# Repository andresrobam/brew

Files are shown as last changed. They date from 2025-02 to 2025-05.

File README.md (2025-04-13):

# brew

Raspberry Pi based brewing controller.\
Written for and tested on a Raspberry Pi 4B running DietPi 9.9, but might work on other combinations.\
Requires docker and docker compose to be installed.
Runs on http://localhost:80. Port can be changed in the `docker-compose` file.

PID logic copied from [hirschmann/pid-autotune](https://github.com/hirschmann/pid-autotune).

## Issues

Fan tachometer signal reading does not work as intended and is hidden in the UI. Will be fixed in a future revision. \
Transistor footprints on the PCB have their pads very close together which makes soldering difficult. Will be changed for wider footprint in a future revision.

## GPIO pins

- GPIO04 (board 7) - Data channel of a DS18B20 temperature sensor (input)
- GPIO12 (board 32) - Fan PWM (output)
- GPIO13 (board 33) - PWM signal to drive the heater through a solid state relay (output)
- GPIO24 (board 18) - Buzzer (output)
- GPIO26 (board 37) - Fan tachometer signal (input)
- GPIO27 (board 13) - Pump relay control (output)

More details about the connections (necessary components and wiring) can be found in the `electronics` sub-directory (open with KiCad).

## Configuring temperature sensor and PWM modules

Add hardware PWM to boot configuration:

```
sudo echo -e "\ndtoverlay=pwm-2chan,pin=12,func=4,pin2=13,func2=4\n" >> /boot/config.txt
```

Add 1-Wire to boot configuration:

```
sudo echo -e "\ndtoverlay=w1-gpio\n" >> /boot/config.txt
```

Reboot:

```
sudo reboot
```

Add modules:

```
sudo modprobe w1-gpio
sudo modprobe w1-therm
```

## Installation

Configure DS18B20 if not alread configured (see previous section).

Install gcc:
```
apt install gcc
```

Navigate to the folder you want to install this application to and clone the repository:
```
git clone https://github.com/andresrobam/brew.git
```

Start the UI:
```
docker compose up -d
```

Navigate to the backend directory, install requirements and start the backend:
```
cd server
pip3 install -r requirements.txt
python3 app.py
```

## Local build

To build and run locally:

```
docker compose -f docker-compose-local.yml up -d
```

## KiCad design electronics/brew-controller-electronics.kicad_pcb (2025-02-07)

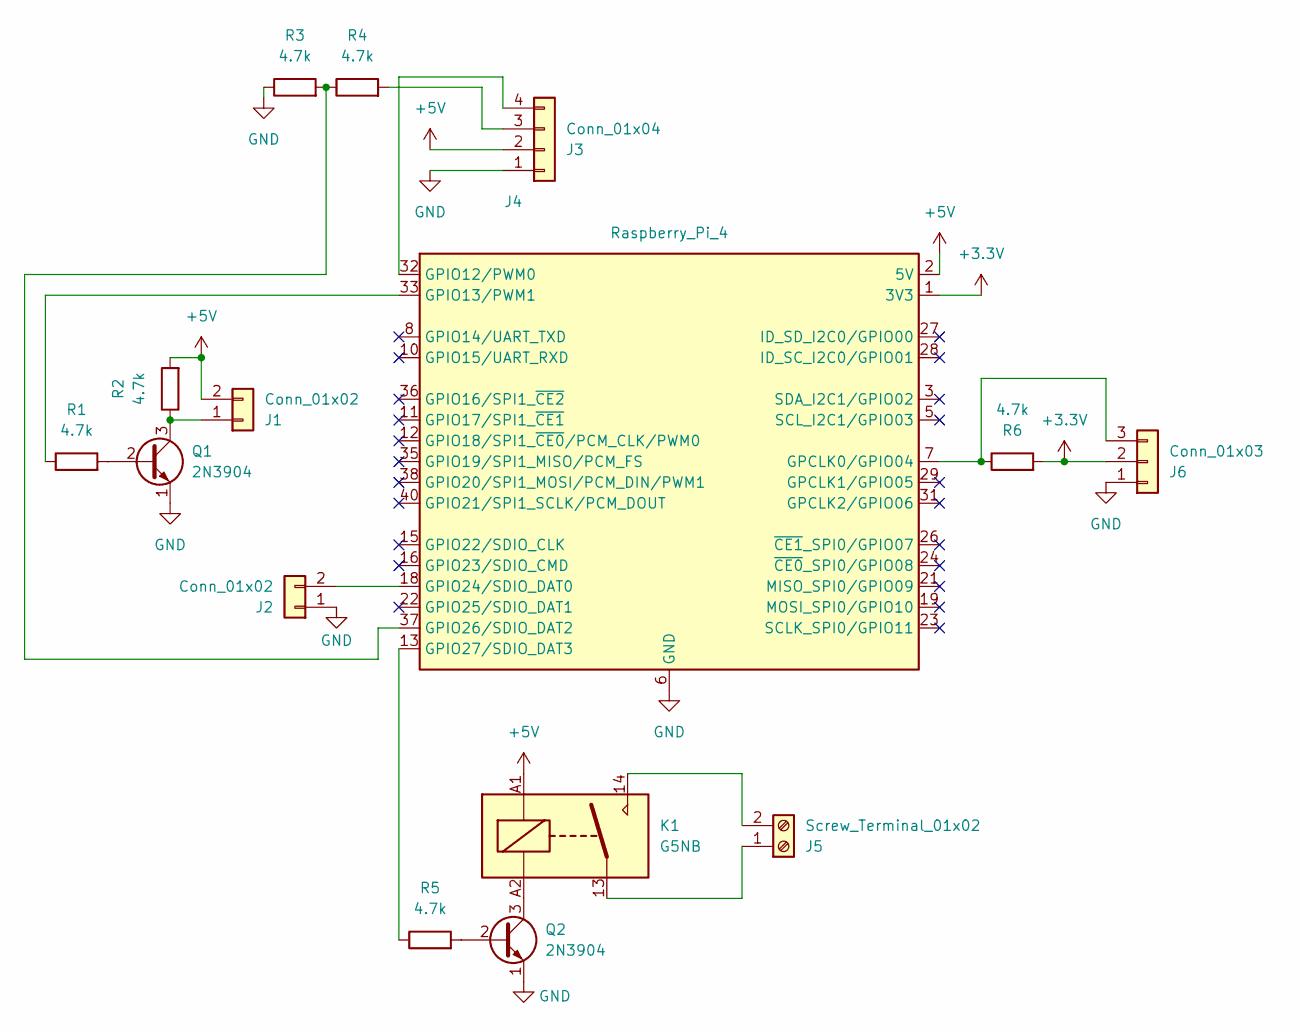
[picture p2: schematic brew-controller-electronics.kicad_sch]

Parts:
J1, J2: Conn_01x02; PinSocket_1x02_P2.54mm_Vertical
J3: Conn_01x04; PinSocket_1x04_P2.54mm_Vertical
J4: Raspberry_Pi_4; PinHeader_2x20_P2.54mm_Vertical
J5: Screw_Terminal_01x02; TerminalBlock_RND_205-00287_1x02_P5.08mm_Horizontal
J6: Conn_01x03; PinHeader_1x03_P2.54mm_Vertical
K1: G5NB; Relay_SPST_Omron_G5NB
Q1, Q2: 2N3904; TO-92_Inline
R1, R2, R3, R4, R5, R6: 4.7k; R_Axial_DIN0207_L6.3mm_D2.5mm_P10.16mm_Horizontal

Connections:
+3.3V: J4.1 (3V3), J4.17 (3V3), J6.2, R6.2
+5V: J1.2, J3.2, J4.2 (5V), J4.4 (5V), K1.A1, R2.2
GND: J2.1, J3.1, J4.6 (GND), J4.9 (GND), J4.14 (GND), J4.20 (GND), J4.25 (GND), J4.30 (GND), J4.34 (GND), J4.39 (GND), J6.1, Q1.1 (E), Q2.1 (E), R3.1
unnamed: J1.1, Q1.3 (C), R2.1
unnamed: J2.2, J4.18 (GPIO24/SDIO_DAT0)
unnamed: J3.3, R4.2
unnamed: J3.4, J4.32 (GPIO12/PWM0)
unnamed: J4.7 (GPCLK0/GPIO04), J6.3, R6.1
unnamed: J4.33 (GPIO13/PWM1), R1.1
unnamed: J4.37 (GPIO26/SDIO_DAT2), R3.2, R4.1
unnamed: J4.13 (GPIO27/SDIO_DAT3), R5.1
unnamed: J5.1, K1.13
unnamed: J5.2, K1.14
unnamed: Q1.2 (B), R1.2
unnamed: Q2.2 (B), R5.2
unnamed: K1.A2, Q2.3 (C)

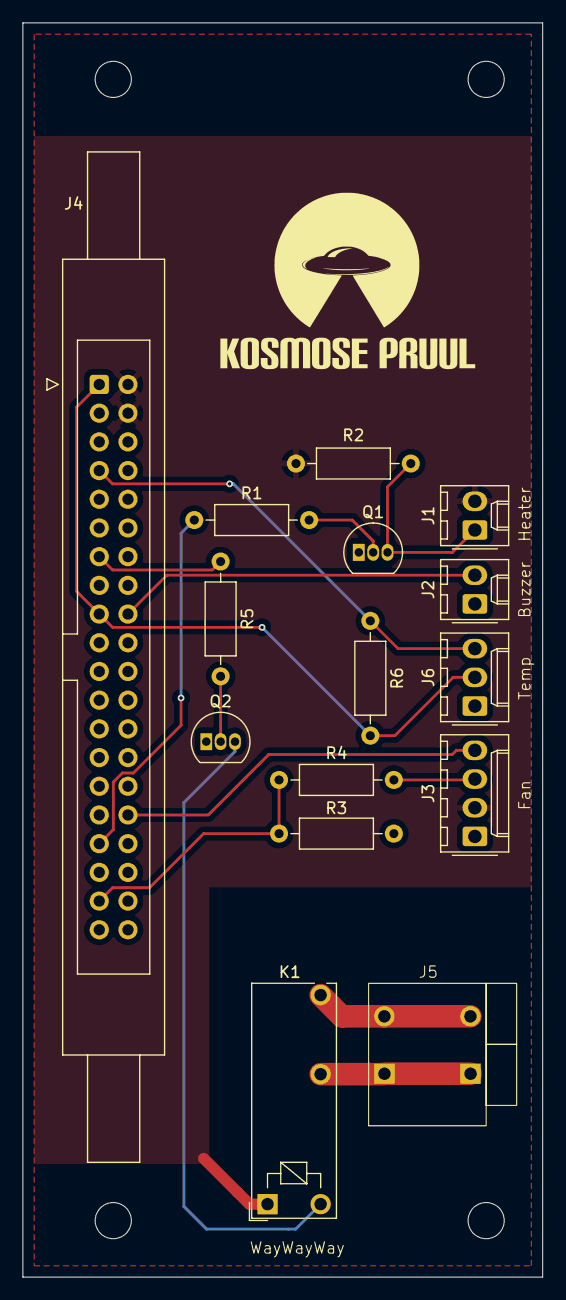
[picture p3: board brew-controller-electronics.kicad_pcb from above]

Board: 2 copper layers, 46.0 x 111.0 mm, 15 parts (0 on the bottom side), 16 nets.

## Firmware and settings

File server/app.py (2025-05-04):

import glob
import RPi.GPIO as GPIO
import re
import traceback
import json
import time
import datetime
import atexit
import threading
import netifaces
import asyncio

from rpi_hardware_pwm import HardwarePWM
from math import floor
from flask import Flask, request
from flask_cors import CORS
from pid import PID
from autotune import PIDAutotune
from apscheduler.schedulers.background import BackgroundScheduler
from logging.config import dictConfig
from datetime import datetime, timezone

OK_RESPONSE = "{\"status\": \"OK\"}", 200, {'Content-Type': 'application/json'}
BAD_REQUEST_RESPONSE = "{\"status\": \"BAD_REQUEST\"}", 400, {'Content-Type': 'application/json'}

dictConfig({
    'version': 1,
    'formatters': {'default': {
        'format': '[%(asctime)s] %(levelname)s in %(module)s: %(message)s',
    }},
    'handlers': {'wsgi': {
        'class': 'logging.StreamHandler',
        'stream': 'ext://flask.logging.wsgi_errors_stream',
        'formatter': 'default'
    }},
    'root': {
        'level': 'INFO',
        'handlers': ['wsgi']
    }
})

GPIO.setmode(GPIO.BOARD)

pump_pin = 13
fan_tach_pin = 37
buzzer_pin = 18

GPIO.setup(pump_pin, GPIO.OUT)
GPIO.setup(buzzer_pin, GPIO.OUT)
GPIO.setup(fan_tach_pin, GPIO.IN, pull_up_down=GPIO.PUD_OFF)

tach_counter = 0

def increment_tach_counter():
    global tach_counter
    tach_counter += 1

#GPIO.add_event_detect(fan_tach_pin, GPIO.RISING, callback=increment_tach_counter)

fan_pwm = HardwarePWM(pwm_channel=0, hz=20000, chip=0)
fan_pwm.start(100)

heater_pwm = HardwarePWM(pwm_channel=1, hz=50, chip=0)
heater_pwm.start(0)

mode = "off"
pump = False

has_temperature_sensor_error = True
previous_time = 0.0
temperature = 0.0
previous_temperature = temperature
initial_setpoint = 65.0
fan_power = 100
setpoint = initial_setpoint
boil_threshold = 99.7
boil_power = 50.0
previous_duty_cycle = 0.0
duty_cycle = 0.0
last_fan_check = 0
fan_rpm = 0

timestamps = []
temperature_history = []
setpoint_history = []
duty_cycle_history = []

k_p = 1.0
k_i = 1.0
k_d = 1.0

alarm_armed = False
boil_achieved = False

pid = None
tuner = None
selected_tuning_mode = None
peak_count = 0
messages = []
logs = []

sample_time = 1.0

app = Flask("brew")
base_url = "/api"
CORS(app)

lock = threading.Lock()

def add_log(message):
    logs.append(dict(millis=get_current_timestamp(), text=message))
    if len(logs) > 50:
        logs.pop(0)

def log_info(message):
    app.logger.info(message)
    add_log(message)

def log_error(message):
    app.logger.error(message)
    add_log(message)

def load_settings():
    global initial_setpoint
    global fan_power
    global setpoint
    global boil_threshold
    global boil_power
    global k_p
    global k_i
    global k_d
    try:
        with open('config.json', 'r') as file:
            settings = json.load(file)    
            initial_setpoint = settings["initial_setpoint"]
            fan_power = settings["fan_power"]
            setpoint = initial_setpoint
            boil_threshold = settings["boil_threshold"]
            boil_power = settings["boil_power"]
            k_p = settings["k_p"]
            k_i = settings["k_i"]
            k_d = settings["k_d"]
        log_info("Initialized settings from config.json!")
    except Exception:
        log_error("Failed initializing setting from config.json, using defaults!")
        log_error(traceback.format_exc())
        pass
    set_fan_power()

def save_settings():
    settings = {}
    settings["initial_setpoint"] = initial_setpoint
    settings["fan_power"] = fan_power
    settings["boil_threshold"] = boil_threshold
    settings["boil_power"] = boil_power
    settings["k_p"] = k_p
    settings["k_i"] = k_i
    settings["k_d"] = k_d
    with open('config.json', 'w+') as file:
        file.write(json.dumps(settings))
    log_info("Wrote to config.json!")

def initialize_pid():
    global pid
    pid = PID(sample_time, k_p, k_i, k_d)

def reset_pid():
    global pid
    if pid is None:
        return
    log_info("Resetting PID")
    initialize_pid()

def get_current_timestamp():
    return floor((datetime.now(timezone.utc) - datetime(1970, 1, 1, tzinfo=timezone.utc)).total_seconds() * 1000)

def set_pump_status(status):
    global pump
    pump = status
    if status: 
        log_info("Pump turned ON")
        GPIO.output(pump_pin, GPIO.HIGH)
    else:
        log_info("Pump turned OFF")
        GPIO.output(pump_pin, GPIO.LOW)

def set_pid_status(status):
    global pid
    if status:
        initialize_pid()
        log_info("PID turned ON")
    else:
        pid = None
        log_info("PID turned OFF")

async def buzzer_off():
    await asyncio.sleep(0.5)
    GPIO.output(buzzer_pin, GPIO.LOW)

def buzz():
    log_info("BUZZ")
    GPIO.output(buzzer_pin, GPIO.HIGH)
    asyncio.run(buzzer_off())

def handle_boil():
    global duty_cycle
    global boil_achieved
    if mode != "boil":
        return
    if not boil_achieved:
        duty_cycle = 100
        if temperature >= boil_threshold:
            buzz()
            boil_achieved = True
    if boil_achieved:
        duty_cycle = boil_power

def set_mode(new_mode):
    log_info(f"Mode set to: {new_mode}")
    global mode
    global duty_cycle
    global alarm_armed
    global boil_achieved
    global tuner
    mode = new_mode
    if mode == "off":
        set_pid_status(False)
        duty_cycle = 0
        alarm_armed = False
        tuner = None
    elif mode == "auto":
        reset_pid()
        set_pid_status(True)
        alarm_armed = True
        duty_cycle = 0
        tuner = None
    elif mode == "manual":
        set_pid_status(False)
        alarm_armed = False
        tuner = None
    elif mode == "boil":
        set_pid_status(False)
        alarm_armed = False
        boil_achieved = False
        handle_boil()
        tuner = None
    elif mode == "tuning":
        alarm_armed = False
        duty_cycle = 0
        set_pid_status(False)
        global peak_count
        peak_count = 0
        tuner = PIDAutotune(sample_time, initial_setpoint, 100)

def calculate_fan_rpm():
    global last_fan_check

    if last_fan_check == 0:
        last_fan_check = get_current_timestamp()
        return
    
    global fan_rpm
    global tach_counter
    current_timestamp = get_current_timestamp()
    fan_rpm = tach_counter / ((current_timestamp - last_fan_check)/60000)
    tach_counter = 0
    last_fan_check = current_timestamp

@app.route(base_url+"/status", methods = ["GET"])
def get_status():
    with lock:
        response = {}
        response["mode"] = mode
        response["pump"] = pump
        response["temperature"] = None if has_temperature_sensor_error else temperature
        response["setpoint"] = setpoint
        response["dutyCycle"] = duty_cycle
        response["chartX"] = timestamps
        response["chartTemperatureY"] = temperature_history
        response["chartSetpointY"] = setpoint_history
        response["chartDutyCycleY"] = duty_cycle_history
        response["boilAchieved"] = boil_achieved
        if not tuner is None:
            response["autotunePeakCount"] = tuner.peak_count
        return json.dumps(response), 200, {'Content-Type': 'application/json'}

@app.route(base_url+"/setpoint", methods = ["PUT"])
def put_setpoint():
    with lock:
        if has_temperature_sensor_error:
            return BAD_REQUEST_RESPONSE
        global setpoint
        global alarm_armed
        set_mode("auto")
        setpoint = float(request.args.get("setpoint"))
        alarm_armed = True
    return OK_RESPONSE

@app.route(base_url+"/duty-cycle", methods = ["PUT"])
def put_duty_cycle():
    with lock:
        if has_temperature_sensor_error:
            return BAD_REQUEST_RESPONSE
        global duty_cycle
        new_duty_cycle = float(request.args.get("dutyCycle"))
        set_mode("manual" if new_duty_cycle > 0 else "off")
        duty_cycle = new_duty_cycle
    return OK_RESPONSE

@app.route(base_url+"/mode", methods = ["PUT"])
def put_mode():
    with lock:
        if has_temperature_sensor_error:
            return BAD_REQUEST_RESPONSE
        new_tuning_mode = request.args.get("tuningMode")
        if not new_tuning_mode is None:
            global selected_tuning_mode
            selected_tuning_mode = new_tuning_mode
            log_info(f"Selected tuning mode: {selected_tuning_mode}")
        set_mode(request.args.get("mode"))
    return OK_RESPONSE
    
@app.route(base_url+"/pump", methods = ["PUT"])
def put_pump():
    with lock:
        set_pump_status(request.args.get("pump").lower() == "true")
    return OK_RESPONSE

@app.route(base_url+"/settings/pid", methods = ["GET"])
def get_pid_settings():
    with lock:
        response = {}
        response["p"] = k_p
        response["i"] = k_i
        response["d"] = k_d
        return json.dumps(response), 200, {'Content-Type': 'application/json'}

@app.route(base_url+"/settings/pid", methods = ["PUT"])
def put_pid_settings():
    with lock:
        global k_p
        global k_i
        global k_d
        k_p = float(request.args.get("p"))
        k_i = float(request.args.get("i"))
        k_d = float(request.args.get("d"))
        save_settings()
        reset_pid()
    return OK_RESPONSE

@app.route(base_url+"/settings/boil", methods = ["GET"])
def get_temperature_settings():
    with lock:
        response = {}
        response["boilThreshold"] = boil_threshold
        response["boilPower"] = boil_power
        return json.dumps(response), 200, {'Content-Type': 'application/json'}

@app.route(base_url+"/settings/boil", methods = ["PUT"])
def put_temperature_settings():
    with lock:
        global boil_threshold
        global boil_power
        boil_threshold = float(request.args.get("boilThreshold"))
        boil_power = float(request.args.get("boilPower"))
        save_settings()
        if mode == "boil":
            set_mode("boil")
    return OK_RESPONSE

@app.route(base_url+"/settings/other", methods = ["GET"])
def get_other_settings():
    with lock:
        response = {}
        response["initialSetpoint"] = initial_setpoint
        response["fanPower"] = fan_power
        return json.dumps(response), 200, {'Content-Type': 'application/json'}

@app.route(base_url+"/settings/other", methods = ["PUT"])
def put_other_settings():
    with lock:
        global initial_setpoint
        global fan_power
        initial_setpoint = float(request.args.get("initialSetpoint"))
        fan_power = float(request.args.get("fanPower"))
        set_fan_power()
        save_settings()
    return OK_RESPONSE
        
@app.route(base_url+"/messages", methods = ["GET"])
def get_messages():
    with lock:
        global messages        
        response = []
        response += messages
        messages = []
        return response, 200, {'Content-Type': 'application/json'}
        
@app.route(base_url+"/info", methods = ["GET"])
def get_info():
    with lock:
        global messages        
        response = {}
        response["logs"] = logs
        cpuTemperature = get_cpu_temperature()
        if not cpuTemperature is None:
            response["cpuTemperature"] = cpuTemperature
        ip = get_ip()
        if not ip is None:
            response["ip"] = ip
        response["startMillis"] = start_millis
        response["fanRpm"] = fan_rpm
        return response, 200, {'Content-Type': 'application/json'}

@app.route(base_url+"/health", methods = ["GET"])
def health():
    return "{\"status\": \"up\"}", 200, {'Content-Type': 'application/json'}

def save_chart_data():
    timestamps.append(get_current_timestamp())
    temperature_history.append(None if has_temperature_sensor_error else temperature)
    setpoint_history.append(None if pid is None else setpoint)
    duty_cycle_history.append(duty_cycle)

    if len(timestamps) > 3600:
        timestamps.pop(0)
        temperature_history.pop(0)
        setpoint_history.pop(0)
        duty_cycle_history.pop(0)

def handle_pid():
    if pid is None:
        return
    global duty_cycle
    duty_cycle = pid.calc(temperature, setpoint)

def handle_autotune():
    global tuner
    if tuner is None:
        return
    global duty_cycle
    tuner.run(temperature)
    duty_cycle = tuner.output
    global peak_count
    new_peak_count = tuner.peak_count
    if new_peak_count != peak_count:
        peak_count = new_peak_count
        log_info(f"Autotune peak count: {peak_count}")
    if tuner.state == PIDAutotune.STATE_SUCCEEDED or tuner.state == PIDAutotune.STATE_FAILED or tuner.state == PIDAutotune.STATE_OFF:
        buzz()
        message = None
        if tuner.state == PIDAutotune.STATE_SUCCEEDED:
            message = dict(text="Autotune successful", style="success")
            global k_p
            global k_i
            global k_d
            
            for tuning_mode in tuner.tuning_rules:
                params = tuner.get_pid_parameters(tuning_mode)
                log_info(F"Tuning mode: {tuning_mode}")
                log_info(F"Kp: {params.Kp}")
                log_info(F"Ki: {params.Ki}")
                log_info(F"Kd: {params.Kd}")

                if tuning_mode == selected_tuning_mode:
                    k_p = params.Kp
                    k_i = params.Ki
                    k_d = params.Kd

            tuner = None
            save_settings()
        elif tuner.state == PIDAutotune.STATE_FAILED:
            message = dict(text="Autotune failed", style="error")
        set_mode("off")
        if not message is None:
            log_info(message["text"])
            messages.append(message)

def get_cpu_temperature():
    try:
        with open('/sys/class/thermal/thermal_zone0/temp') as file:
            return float(file.read().strip())/1000
    except Exception:
        return None

def get_ip():
    try:
        return netifaces.ifaddresses('wlan0')[2][0]['addr']
    except Exception:
        return None

def get_temperature():
    global has_temperature_sensor_error
    global temperature

    try:
        base_dir = '/sys/bus/w1/devices/'
        device_folder = glob.glob(base_dir + '28*')[0]
        device_file = device_folder + '/w1_slave'
        with open(device_file, 'r') as file:
            result = re.search('.*t=(-?\d+).*', file.read())
            if result is None:
                has_temperature_sensor_error = True

            else:
                temperature = float(result.group(1))/1000
                has_temperature_sensor_error = False
    except Exception:
        has_temperature_sensor_error = True

    if has_temperature_sensor_error and mode != "off":
        message = dict(text="Temperature sensor error, turning off!", style="error")
        log_error(message["text"])
        messages.append(message)
        set_mode("off")


def set_heater_pwm():
    global previous_duty_cycle
    if previous_duty_cycle == duty_cycle:
        return
    previous_duty_cycle = duty_cycle
    log_info(f"Setting heater duty cycle to {duty_cycle}")
    heater_pwm.change_duty_cycle(duty_cycle)

def set_fan_power():
    log_info(f"Setting fan power to {fan_power}")
    fan_pwm.change_duty_cycle(fan_power)

def handle_alarm():
    global alarm_armed
    if alarm_armed and ((previous_temperature < setpoint and temperature >= setpoint) or (previous_temperature > setpoint and temperature <= setpoint)):
        buzz()
        alarm_armed = False

def handle_time():
    global previous_time
    global timestamps
    global temperature_history
    global setpoint_history
    global duty_cycle_history
    new_time = time.time()
    if new_time < previous_time or new_time - previous_time > 5:
        log_info("Time jump detected, emptying charts")
        timestamps = []
        temperature_history = []
        setpoint_history = []
        duty_cycle_history = []
    previous_time = new_time

def loop():
    with lock:
        global previous_temperature
        previous_temperature = temperature
        handle_time()
        get_temperature()
        handle_pid()
        handle_boil()
        handle_autotune()
        set_heater_pwm()
        handle_alarm()
        calculate_fan_rpm()
        save_chart_data()

load_settings()

start_millis = get_current_timestamp()
previous_time = time.time()

scheduler = BackgroundScheduler()
scheduler.add_job(func=loop, trigger="interval", seconds=1)
scheduler.start()

atexit.register(lambda: scheduler.shutdown())

if __name__ == '__main__':
    app.run(threaded = True, host="0.0.0.0")

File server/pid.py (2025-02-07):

from time import time
import logging

class PID(object):

    def __init__(self, sampletime, kp, ki, kd, out_min=0.0,
                 out_max=100.0, time=time):
        if kp is None:
            raise ValueError('kp must be specified')
        if ki is None:
            raise ValueError('ki must be specified')
        if kd is None:
            raise ValueError('kd must be specified')
        if sampletime <= 0:
            raise ValueError('sampletime must be greater than 0')
        if out_min >= out_max:
            raise ValueError('out_min must be less than out_max')

        self._logger = logging.getLogger(type(self).__name__)
        self._Kp = kp
        self._Ki = ki * sampletime
        self._Kd = kd / sampletime
        self._sampletime = sampletime * 1000
        self._out_min = out_min
        self._out_max = out_max
        self._integral = 0
        self._last_input = 0
        self._last_output = 0
        self._last_calc_timestamp = 0
        self._time = time

    def calc(self, input_val, setpoint):
        now = self._time() * 1000

        if (now - self._last_calc_timestamp) < self._sampletime:
            return self._last_output

        # Compute all the working error variables
        error = setpoint - input_val
        input_diff = input_val - self._last_input

        # In order to prevent windup, only integrate if the process is not saturated
        if self._last_output < self._out_max and self._last_output > self._out_min:
            self._integral += self._Ki * error
            self._integral = min(self._integral, self._out_max)
            self._integral = max(self._integral, self._out_min)

        p = self._Kp * error
        i = self._integral
        d = -(self._Kd * input_diff)

        # Compute PID Output
        self._last_output = p + i + d
        self._last_output = min(self._last_output, self._out_max)
        self._last_output = max(self._last_output, self._out_min)

        # Log some debug info
        self._logger.debug('P: {0}'.format(p))
        self._logger.debug('I: {0}'.format(i))
        self._logger.debug('D: {0}'.format(d))
        self._logger.debug('output: {0}'.format(self._last_output))

        # Remember some variables for next time
        self._last_input = input_val
        self._last_calc_timestamp = now
        return self._last_output

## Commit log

2025-02-07 Initial commits.
    [brew-controller-electronics.kicad_pcb, brew-controller-electronics.kicad_sch]
2025-02-13 Add fan RPM
2025-02-23 Temperature reading logic.
2025-02-23 Use hardware PWM for fan and heater.
2025-02-23 Add fan rpm logic
2025-02-23 Remove interrupt debounce.
2025-02-23 Use pull-down resistor for tach and rising edge for interrupt.
2025-02-23 Add debug print.
2025-02-23 Disable pull-up resistor.
2025-04-13 Round temperature
2025-05-04 Fix temperature reading when >= 100C
    [app.py]
2025-05-04 Format temperature and duty cycle values
